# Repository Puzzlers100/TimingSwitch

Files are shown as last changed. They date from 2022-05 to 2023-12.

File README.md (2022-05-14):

## __Timing Vex Competition Switch__  

Picture of the Competition switch attached to a controller

This is a reposity for the information about how to build and use Timing Competition Switch  

If you are interested in contacting me to buy one, please use this [Whatsapp Link](https://wa.me/16503987996), or DM me on Vex Forum under the username Puzzlers100.
#### USE  

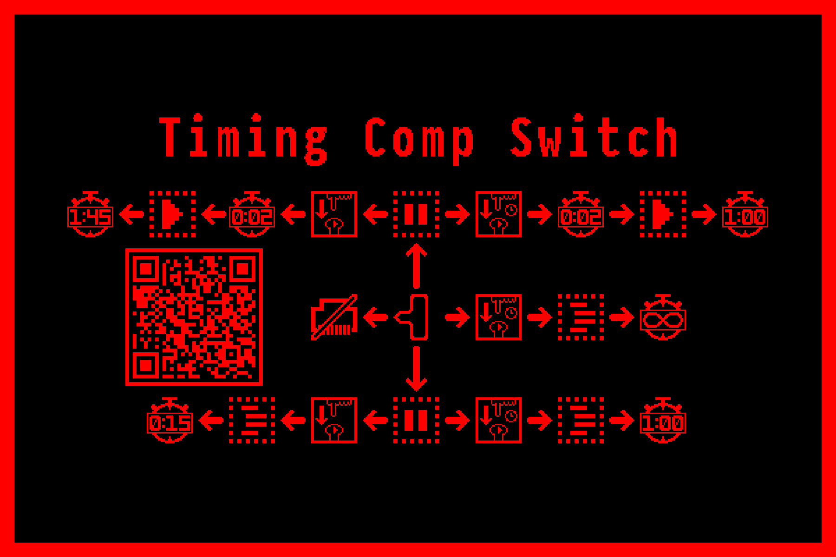
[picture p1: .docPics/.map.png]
Map for Competition Switch Usage


The Slider has 3 positions, up, down or center. In each position, pressig the button does something different, as does holding it for half a second before releasing  
- UP - DRIVER Position, the robot is disabled
    - Push - Starts a 1 minute and 45 second Driver period, after 1 and a half seconds of delay, simulating a match (though only - for one person)
    - Hold - Starts a 1 minute skills match, after 1 and half seconds of delay
- CENTER - DISCONNECTED - the robot doesn't see the compswitch.
    - HOLD - Starts and infinate Auton period. This can be disabled by pressing the button again
- DOWN - AUTON Position, the robot is disabled
    - Push - Starts a 15 second Autonomous period, simulating a match
    - HOLD - Starts a 1 minute Autonomous skills period  
If the robot is enabled, pressing the button or moving the slider will immedietly disable it, if your auton is going to run into something, you can stop it.
#### BUILD GUIDE
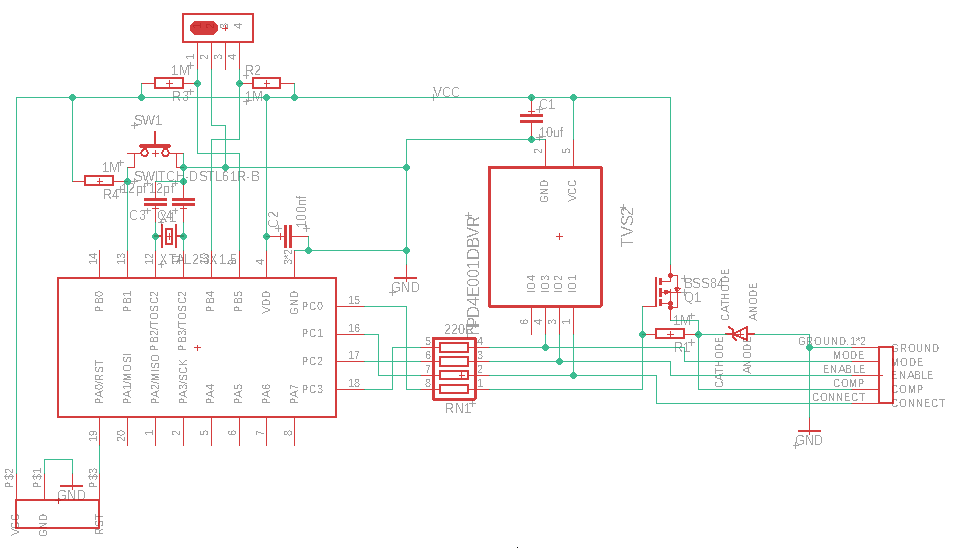
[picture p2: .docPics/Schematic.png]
Schematic for the competition switch


1. Get a circuit board - These can be manufactured by a lot of different companies, however the pre-made gerbers are for JLCPCB, and also include files needed for PCB assembly, if desired. OSH park can use the EAGLE files directly, but if you want to use another manufacturer, you can remake the Gerbers in EAGLE to their specification. Eagle can be downloaded for free from autodesk, though you may need to make an account.       

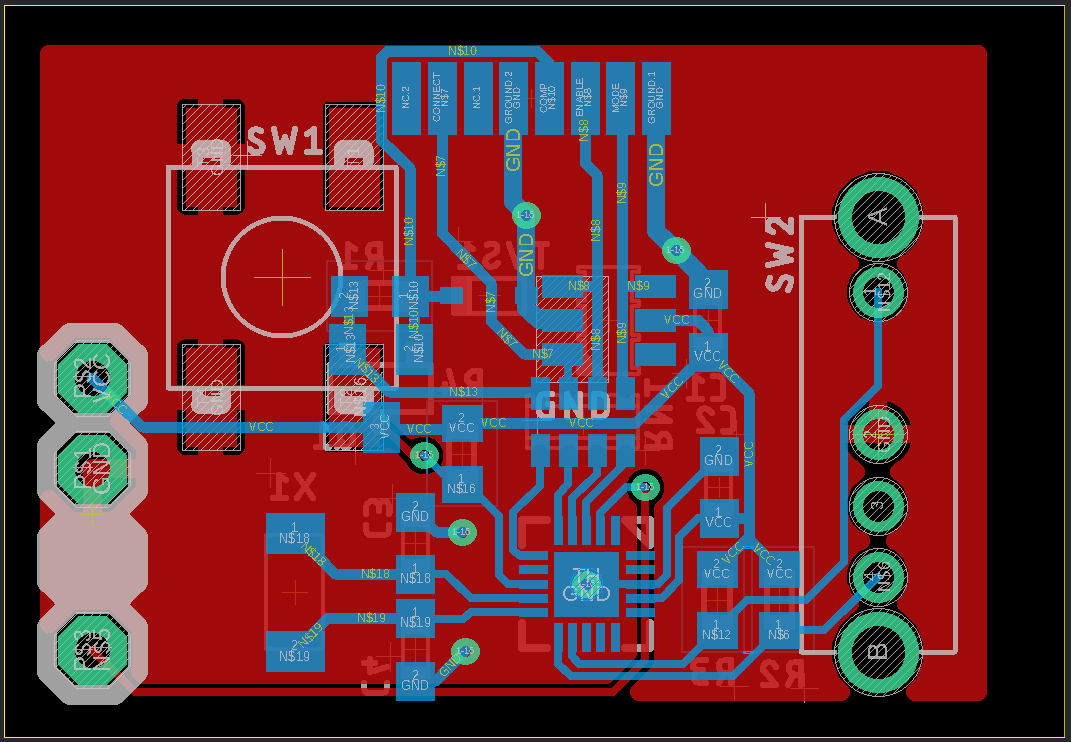
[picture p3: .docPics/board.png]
An image of the circuit Board


2. Buy the needed parts - There is a BOM with part numbers included, however most parts can be substituted if you can find something with the same specifications and footprint   

3. Soldering - Have fun with this step, the parts are tiny and close to each other, so watch out for shorts. I recommend doing the surface mount first, then the slider and button, and the RJ-45 cable last. The pad order for the Rj-45 cable is 1,2,3,6,4,5,7,8, as it is otimized to be used with a flat CAT6 cable, which keeps 3 and 6 together. Pin 1 is ground, and the closest pin to the sliding switch. I recommend testing it, then covering the wires with UV-curing epoxy to protect it. 

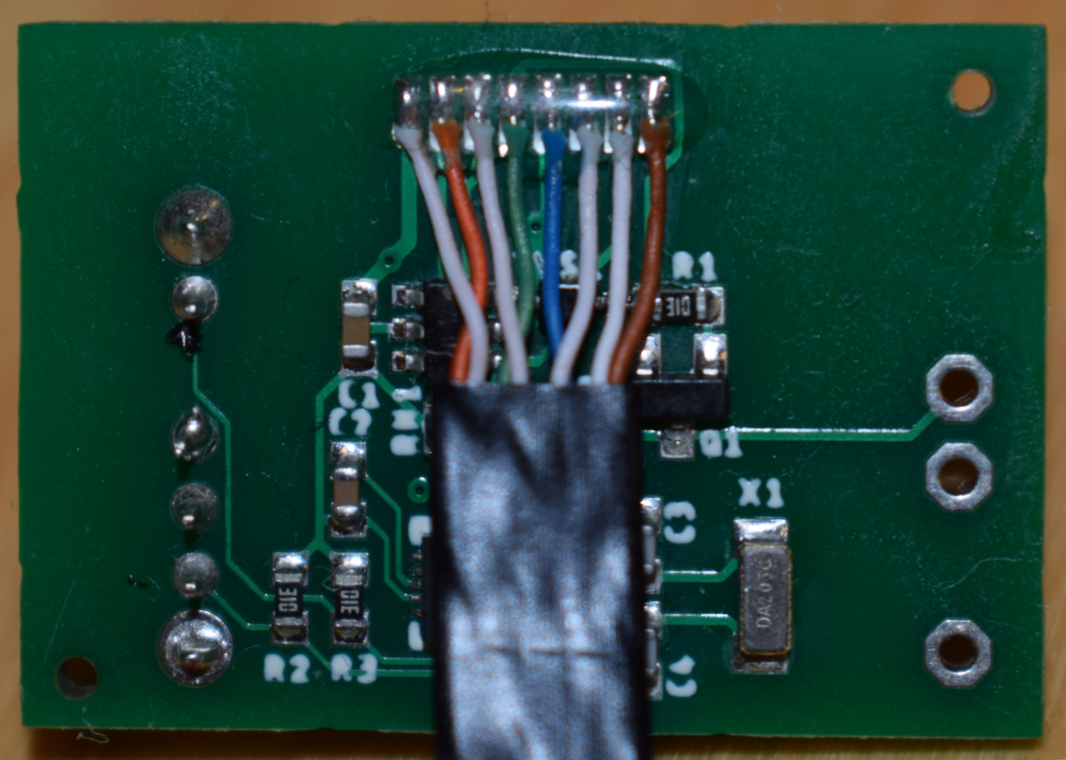
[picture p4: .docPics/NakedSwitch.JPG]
An image of the wiring for the Cat6 cable connecting to the controller

  
4.  Flashing the Software - The board uses an UPDI programming interface, with the following pinnout 1: VCC, 2: GND, 3: BLANK, 4: UPDI_DATA. The makefile is set up to use an ATtiny416 xplained nano as a programmer. Run `make` in the Software folder to build the firmware, or directly `make prod` to upload it and program the fuses. You may need the latest version of AVRdude and AVR-gcc with the Microchip ATtiny pack installed. 

5.  3D print the case - If you don't have a 3D printer, look around the local area and see if there is a public makerspace. Some public libraries may also have them. If you want the text, it can be done with a single color printer by printing just the two layers of text, then switching and printing the whole switch around it

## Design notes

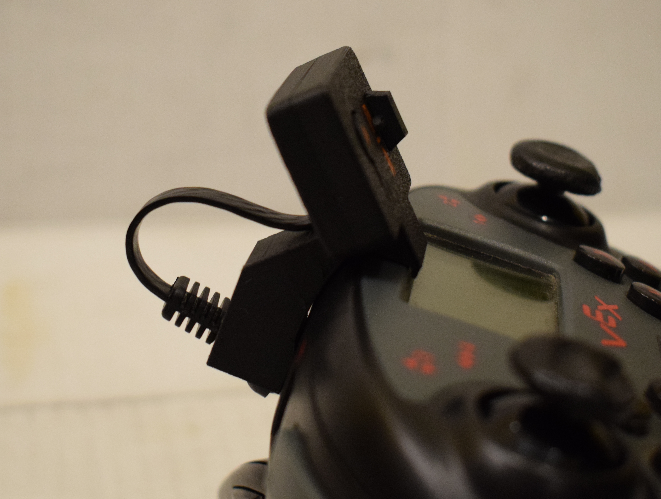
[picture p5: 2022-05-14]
.docPics/SideCont.JPG

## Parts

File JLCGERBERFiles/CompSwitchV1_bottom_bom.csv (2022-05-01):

Comment | Designator | Footprint | LCSC Part #
1M | R1 | R0603 | C22935
4x220R | RN1 | CTS742C083 | C29719
6pF | C1 C5 | 0603-UNI | C37474
32.768 | XATL1 | 1206-UNI | C295064
100nF | C2 C3 C4 | 0603-UNI | C14663
ATTINY861-20MU | IC1 | MLF32-TH | C1339572
BSS84 | Q1 | SOT23 | C699295
D1213A-01WS-7 | D1 | SOD323 | C170167
SOIC8PROGRAMER | PROG | SOIC8PROGRAMER
TPD4E001DRL | U1 | TI-R-PDSO-N6 | C527516
VEX-CONNECT | CONN | VEX-CONNECT

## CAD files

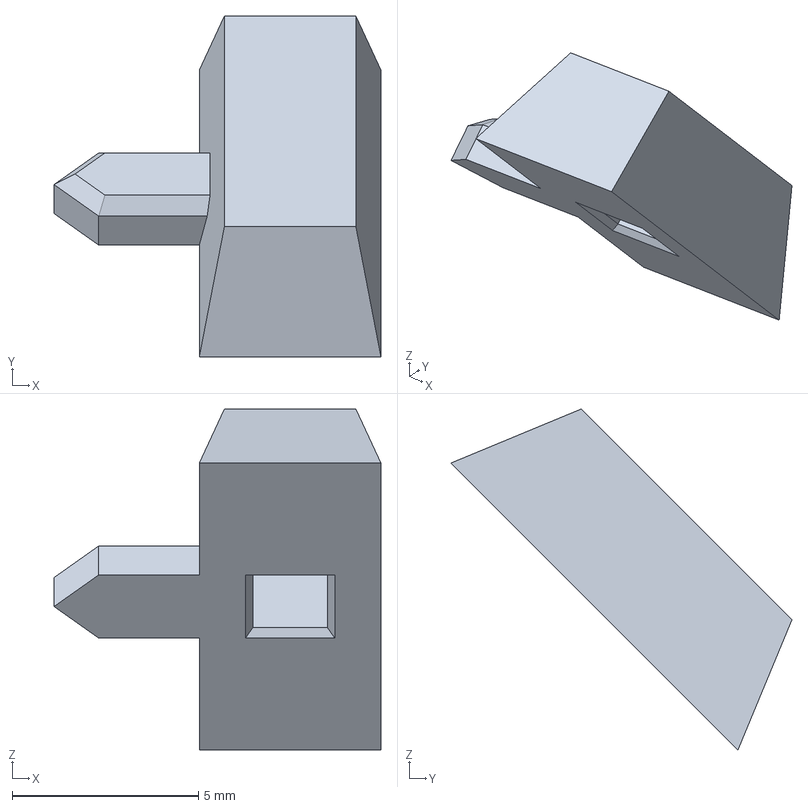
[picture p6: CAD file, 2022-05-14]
3D Parts - 3MF/Slider.3mf
8.78 x 9.16 x 9.16 mm

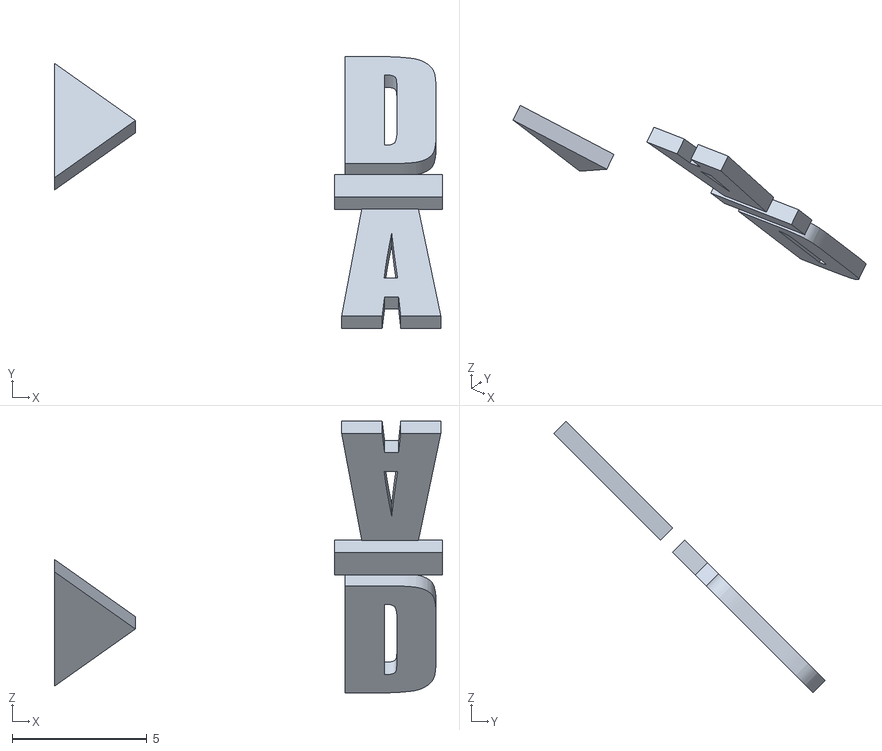
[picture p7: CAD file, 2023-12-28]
3D Parts - STL/Text.stl
14.4 x 10.1 x 10.1

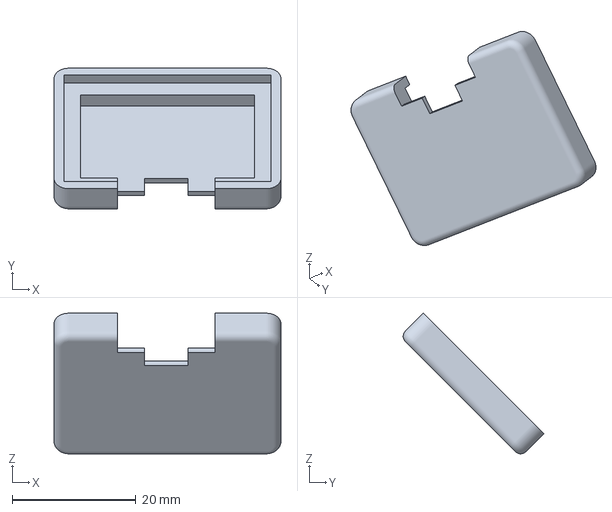
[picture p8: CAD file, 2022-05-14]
3D Parts - 3MF/Back.3mf
36.7 x 22.7 x 22.7 mm

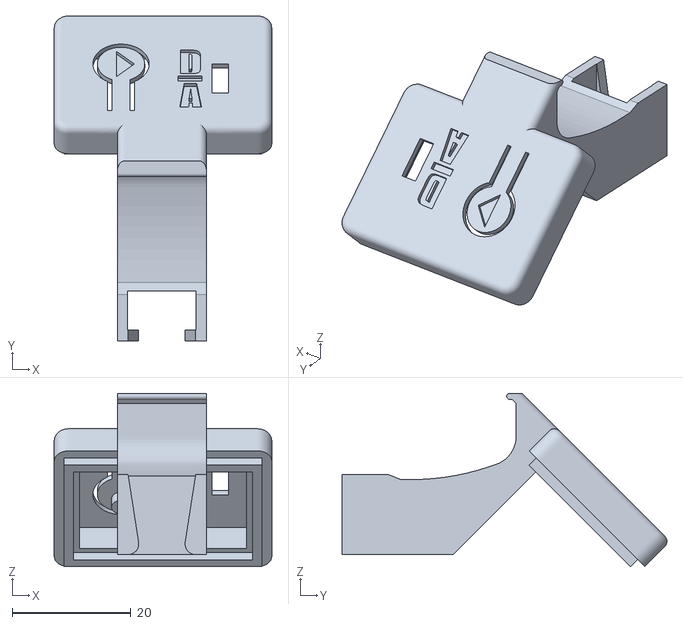
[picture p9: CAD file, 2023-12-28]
3D Parts - STL/BodyWithText.stl
36.7 x 54.8 x 29.2

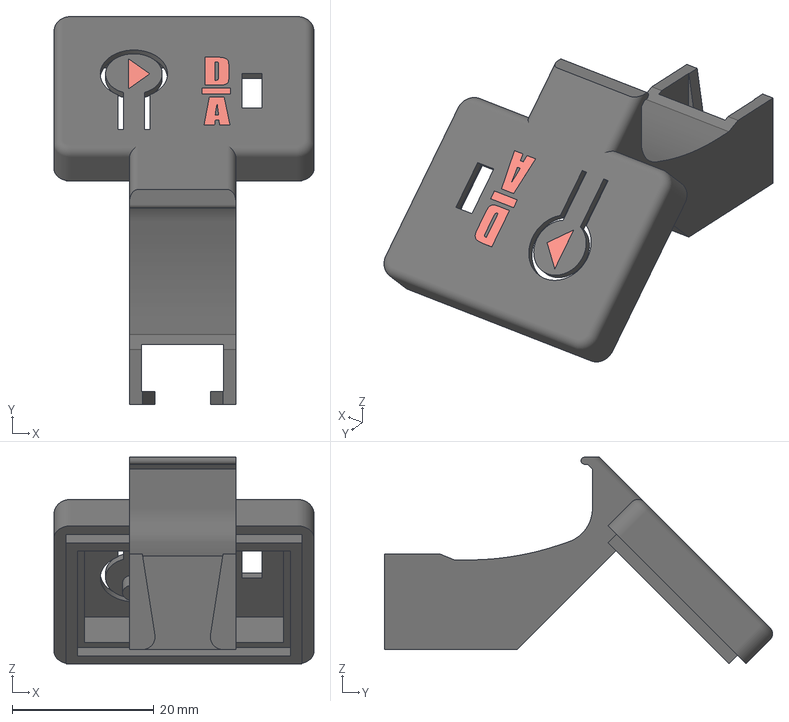
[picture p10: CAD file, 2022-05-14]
3D Parts - 3MF/Clamp.3mf
36.7 x 54.8 x 29.2 mm

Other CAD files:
3D Parts - STL/Body.stl
3D Parts - STL/Back.stl
3D Parts - STL/Slider.stl

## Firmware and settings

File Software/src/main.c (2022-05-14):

/*
 * GccApplication1.cpp
 *
 * Created: 2020-04-21 16:58:47
 * Author : Jakub
 */ 

#include <avr/io.h>
#include <avr/sleep.h>
#include <util/delay.h>

/* Pinout:

    PB4->Button
    PB5->LED (invert)

 * PA0: UPDI
 * PB2/PB3: Xtal
 * PC0: Power enable
 * PC1: DIS/CONNECT
 * PC3: DRIVER/AUTON
 * PC2: ENABLE/DISABLE
 * PA5: INPUT D
 * PA4: INPUT A
 * PB4: RUN
 *
 * DevKit:          }-----------{
 *		Vcc )       GND (
 *              PA0 )       PC3 ( Auton
 *              PA1 )       PC2 ( Disable
 *              PA2 )       PC1 ( Connected
 *              PA3 )       PC0 ( Pwr

 *              A-> ) PA4   PB0 (
 *              D-> ) PA5   PB1 (
 *                  ) PA6   PB2 ( Xtal
 *                  ) PA7   PB3 ( Xtal
 *              LED ) PB5   PB4 ( <-S
 *                  \___________/
 */

// DRV ENB CON PWR
#define PIN_CON PIN1_bp
#define PIN_PWR PIN0_bp
#define PIN_ENB PIN2_bp
#define PIN_DRV PIN3_bp
#define IN_DRV PIN5_bp
#define IN_AUT PIN4_bp
#define IN_STR PIN1_bp

// debugging LED on the devkit
#define OUT_LED PIN5_bp

typedef char bool;
#define true 1
#define false 0

bool selDrive (){
    return !(1 & (PORTB_IN >> IN_DRV));
}

bool selAuton (){
    return !(1 & (PORTB_IN >> IN_AUT));
//    return 1;
}

bool start (){
    return !(1 & (PORTB_IN >> IN_STR));
}

int enabled = 0;

uint16_t tbase = 0;
uint16_t mtime = 0;
uint16_t snap = 0;


int select = 0;
int telemetry = 0;


// Testing initially with pullups, will disable later
#if 0
#define IN_PULLUP PORT_PULLUPEN_bm
#else
#define IN_PULLUP 0
#endif


/**
 * Prepare the system to run off the external 32kHz crystal.
 *
 * The ATTINYx16 always boots off internal 16/20MHz RC oscillator,
 * divided by 6, thus 3.33MHz or 2.67MHz
 * We need to run off the external, precise 32.768kHz crystal oscillator,
 * but that has 300ms startup time. To reduce power consumption during
 * this transition, we can first increase the system clock divisor to 64,
 * then switch to the internal 32kHz R/C oscillator with much faster
 * starup time, and only then try to activate the external xtal.
 */
void setupClocks() {
    // divide by 64 ASAP to reduce power to ~1mA
    CPU_CCP = CCP_IOREG_gc;
    CLKCTRL_MCLKCTRLB = (5 << 1) | 1;

    // Switch to the internal RC 32kHz oscillator
    CPU_CCP = CCP_IOREG_gc;
    CLKCTRL_MCLKCTRLA = CLKCTRL_CLKSEL_OSCULP32K_gc;

    // Reduce power further by disabling unused I/Os
    // and properly configuring all other pins
    //PORTB_OUTSET = (1 << OUT_LED); // turn off LED on the dev kit first

    // prepare all outputs to passive state, incuding the power FET
    PORTC_OUTSET = (1 << PIN_PWR) | (1 << PIN_CON) | (1 << PIN_ENB) | (1 << PIN_DRV); 
    PORTC_DIR = 0xFF; // make the whole PORTC output

    PORTB_PIN0CTRL = PORT_ISC_INPUT_DISABLE_gc; 		// Disable input on PB0
    PORTB_PIN1CTRL = IN_PULLUP | PORT_ISC_INTDISABLE_gc;	// PB1, 4, 5 enabled w/o pullups
    PORTB_PIN4CTRL = IN_PULLUP | PORT_ISC_INTDISABLE_gc;    	// Setup input on PB4 with proper pullup mode
    PORTB_PIN5CTRL = IN_PULLUP | PORT_ISC_INTDISABLE_gc;	// Setup input on PB5 with proper pullup mode
//    PORTB_DIRSET = (1 << OUT_LED);		// Enable LED output

    PORTA_PIN0CTRL = PORT_ISC_INPUT_DISABLE_gc; // Disable PA0
    PORTA_PIN1CTRL = PORT_ISC_INPUT_DISABLE_gc; // Disable PA1
    PORTA_PIN2CTRL = PORT_ISC_INPUT_DISABLE_gc; // Disable PA2
    PORTA_PIN3CTRL = PORT_ISC_INPUT_DISABLE_gc; // Disable PA3
    PORTA_PIN4CTRL = PORT_ISC_INPUT_DISABLE_gc; // Disable PA4
    PORTA_PIN5CTRL = PORT_ISC_INPUT_DISABLE_gc; // Disable PA5
    PORTA_PIN6CTRL = PORT_ISC_INPUT_DISABLE_gc; // Disable PA6
    PORTA_PIN7CTRL = PORT_ISC_INPUT_DISABLE_gc; // Disable PA7


    // Wait for the internal RC to boot
    while (0 == (CLKCTRL_MCLKSTATUS & CLKCTRL_OSC32KS_bm));

    // Disable the divider
    CPU_CCP = CCP_IOREG_gc;
    CLKCTRL_MCLKCTRLB = 0;

    // Request external crystal oscillator, enabling it first
    CPU_CCP = CCP_IOREG_gc;
    // 1k startup time, external crystal, no standby, enabled
    CLKCTRL_XOSC32KCTRLA = CLKCTRL_ENABLE_bm; 

    CPU_CCP = CCP_IOREG_gc;
    CLKCTRL_MCLKCTRLA = CLKCTRL_CLKSEL_XOSC32K_gc;

    // Wait for the internal RC to boot
    while (0 == (CLKCTRL_MCLKSTATUS & CLKCTRL_XOSC32KS_bm));

    // Enable the power FET
    PORTC_OUTCLR = (1 << PIN_PWR);

    // done, running on 32kHz external crystal
}

void setupTimer() {
    // Disable other peripherals
//    PRR = _BV(PRTIM1) | _BV(PRUSI) | _BV(PRADC);
    // clear the counter
    TCA0_SINGLE_CNT = 0;
    TCA0_SINGLE_PER = 0xFFFF;	// should be default after boot

    TCA0_SINGLE_CTRLD = 0; // 16-bit single counter mode
    TCA0_SINGLE_CTRLB = TCA_SINGLE_WGMODE_NORMAL_gc; // normal counter

#if F_CPU == 32768
    // For 32768Hz system clock, use division by 256 to have exactly 128Hz timer clock
    TCA0_SINGLE_CTRLA = TCA_SINGLE_CLKSEL_DIV256_gc | 1; // select DIV256 and enable
#else
    // For 125kHz, use division by 1024 to reach roughly 125Hz
    TCA0_SINGLE_CTRLA = TCA_SINGLE_CLKSEL_DIV1024_gc | 1; // select DIV1024 and enable
#endif

    // After this point, the counter is running
}



uint16_t timer() {
    uint16_t val = TCA0_SINGLE_CNT;
    return val;
}

bool comp(){
    uint16_t val = timer() - snap;
    return (val >= mtime) ? true:false; 
}

/*
void blinkByte(int byte) {
    _delay_ms(1000);

    for (int i=0; i<8; i++) {
        int bit = 0x80 & (byte << i);
	PORTB_OUTCLR = PIN5_bm;
        if (bit) _delay_ms(500); else _delay_ms(100);
	PORTB_OUTSET = PIN5_bm;
        if (bit) _delay_ms(500); else _delay_ms(900);
    }
}
*/

bool isRunning() {
    if ((mtime != 0) && comp()) {
        mtime = 0;
    }
    return mtime > 0;
}

/**
 * State machine states:  (// DRV ENB CON PWR)
 *  Init (temporary:	 1111)
 *  Disconnected	(1110)
 *  Disabled Auton	(0000)
 *  Disabled Driver	(1000)
 *  Running Auton	(0100)
 *  Running Driver      (1100)
 *
 * Inputs:
 *  Auton
 *  Driver
 *  Switch
 *  Time > 0
 */

#define ST_INIT 0x0F
#define ST_DC   0x0E
//#define ST_DC   0x2C
#define ST_D_AUT 0x00
#define ST_D_DRV 0x08
#define ST_T_DRV 0x18
#define ST_R_AUT 0x04
#define ST_I_AUT 0x14
#define ST_R_DRV 0x0C

// 0.5s
#define B_LONG_THRESH 64

// 1.5s for delay between press and actual drive time
#define DRIVE_DELAY 192

void stateMachine() {
    uint8_t state = ST_INIT;

    enum {
        // states:
        B_IDLE,
        B_PRESS,
        B_LONG,
        // events:
        B_CLICK,
        B_EXTRA
    } b_state = B_IDLE;

    uint16_t b_base = 0;

    for (;;) {

        // time since last button press change
        uint16_t debounce = timer() - b_base;

        // resolve start press state
        // idle | press | long | release
        if (debounce < 6) { //47 ms
            if (b_state == B_CLICK || b_state == B_EXTRA) {
                b_state = B_IDLE; // reset after delivering the event
            }
        } else if (b_state == B_IDLE && start()) {
            b_base = timer();
            b_state = B_PRESS;
        } else if (b_state == B_PRESS) {
            if (start()) {
                uint16_t b_len = timer() - b_base;
                if (b_len > B_LONG_THRESH) {
                    b_state = B_LONG;
                }
            } else { // released short press
                b_state = B_CLICK;
                b_base = timer();
            }
        } else if (b_state == B_LONG) {
            if (!start()) { // released long press
                b_state = B_EXTRA;
                b_base = timer();
            }
        } else {
            b_state = B_IDLE; // reset after delivering the event
        }


        switch (state) {
            case ST_INIT:
                if (selDrive()) {
                    state = ST_D_DRV;
                } else if (selAuton()) {
                    state = ST_D_AUT;
                } else {
                    state = ST_DC;
                }
                break;

            case ST_DC:
                if (selDrive()) {
                    state = ST_D_DRV;
                } else if (selAuton()) {
                    state = ST_D_AUT;
                } else if (b_state == B_EXTRA) {
                    // start in middle position, unlimited auton
                    state = ST_I_AUT;
                }
                break;

            case ST_D_DRV:
                // handle mode change first
                if (!selDrive()) {
                    if (selAuton()) {
                        state = ST_D_AUT;
                    } else {
                        state = ST_DC;
                    }
                    break;
                }

                if (b_state == B_CLICK) {
                    snap = timer();
                    mtime = DRIVE_DELAY + 105*128;   // 1:45 match driver run
                    state = ST_T_DRV;
                } else if (b_state == B_EXTRA) {
                    snap = timer();
                    mtime = DRIVE_DELAY + 60*128;   // 1:00 skills driver run
                    state = ST_T_DRV;
                }
                break;

            case ST_T_DRV:                // Initial driver delay
                // handle mode change first
                if (!selDrive()) {
                    if (selAuton()) {
                        state = ST_D_AUT;
                    } else {
                        state = ST_DC;
                    }
                    break;
                }

                if (b_state == B_CLICK) { // cancel while waiting
                    state = ST_D_DRV;
                }

                if ((timer() - snap) > DRIVE_DELAY) {
                    state = ST_R_DRV;
                }
                break;

            case ST_D_AUT:
                // handle mode change first
                if (!selAuton()) {
                    if (selDrive()) {
                        state = ST_D_DRV;
                    } else {
                        state = ST_DC;
                    }
                    break;
                }

                if (b_state == B_CLICK) {
                    snap = timer();
                    mtime = 15*128;   // 0:15 match auton run
                    state = ST_R_AUT;
                } else if (b_state == B_EXTRA) {
                    snap = timer();
                    mtime = 60*128;   // 1:00 skills auton run
                    state = ST_R_AUT;
                }
                break;

            case ST_R_AUT:
                // handle mode change first
                if (!selAuton()) {
                    if (selDrive()) {
                        state = ST_D_DRV;
                    } else {
                        state = ST_DC;
                    }
                    break;
                }

                if (!isRunning() || (b_state == B_CLICK)) { // timeout or cancel
                    state = ST_D_AUT;
                }
                break;

            case ST_I_AUT: // infinite auton
                // handle mode change first
                if (selDrive()) {
                    state = ST_D_DRV;
                } else if (selAuton()) {
                    state = ST_D_AUT;
                } else if (b_state == B_CLICK) { // cancel
                    state = ST_DC;
                }

                break;

            case ST_R_DRV:
                // handle mode change first
                if (!selDrive()) {
                    if (selAuton()) {
                        state = ST_D_AUT;
                    } else {
                        state = ST_DC;
                    }
                    break;
                }

                if (!isRunning() || (b_state == B_CLICK)) { // timeout or cancel
                    state = ST_D_DRV;
                }
                break;
        }

        PORTC_OUT = state;
    }
}


int main(void){
    setupClocks();
    setupTimer();

//    blinkByte(CLKCTRL_MCLKSTATUS);


    stateMachine();
}

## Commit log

2022-05-01 Imported Files
    [CompSwitchV1.GBL, CompSwitchV1.GBO, CompSwitchV1.GBP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]
2022-05-07 3d printing Files
    [Back.3mf, Back.stl, Clamp.3mf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]
2022-05-14 Included JLCPCB generated Gerbers and Eagle Files for PCB
    [CompSwitchV1_bottom_bom.csv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]
2022-05-14 Added additional Picture of pin wiring
2023-12-28 Updated STL files to include text
    [Body.stl, BodyWithText.stl]
